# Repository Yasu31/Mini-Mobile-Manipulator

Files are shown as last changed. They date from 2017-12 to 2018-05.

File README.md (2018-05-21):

# Mini Mobile Manipulator
storage for Individual Projects(自主プロ) at UTokyo

## [Progress is documented in the wiki.](https://github.com/Yasu31/fantastic-octo-parakeet/wiki)

## demo
general run-through of robot
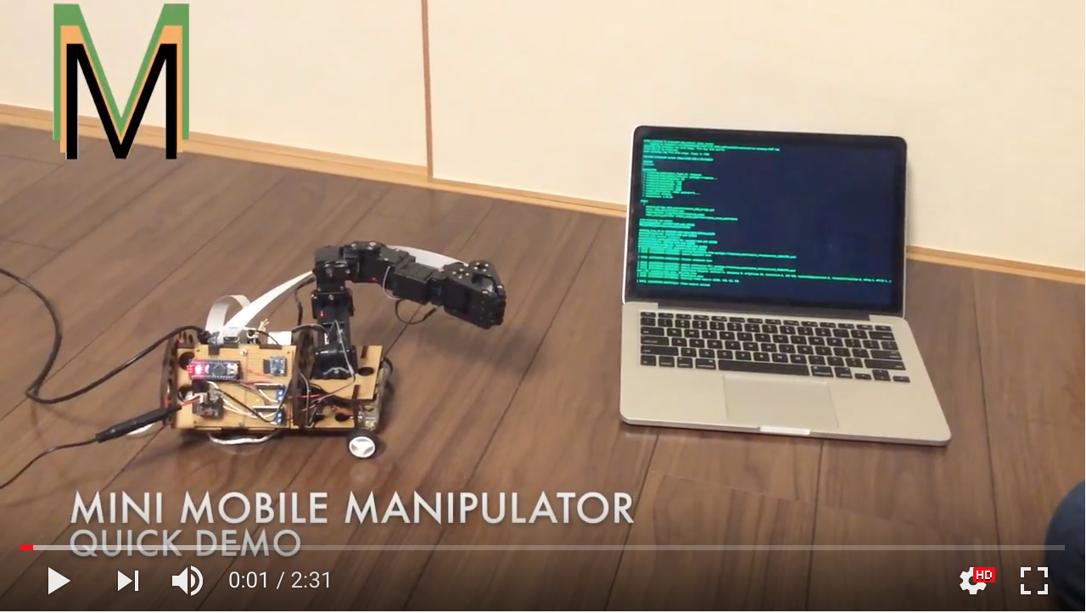
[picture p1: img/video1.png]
(https://www.youtube.com/watch?v=AJrDMAA22wg)


pick up trash(kind of)
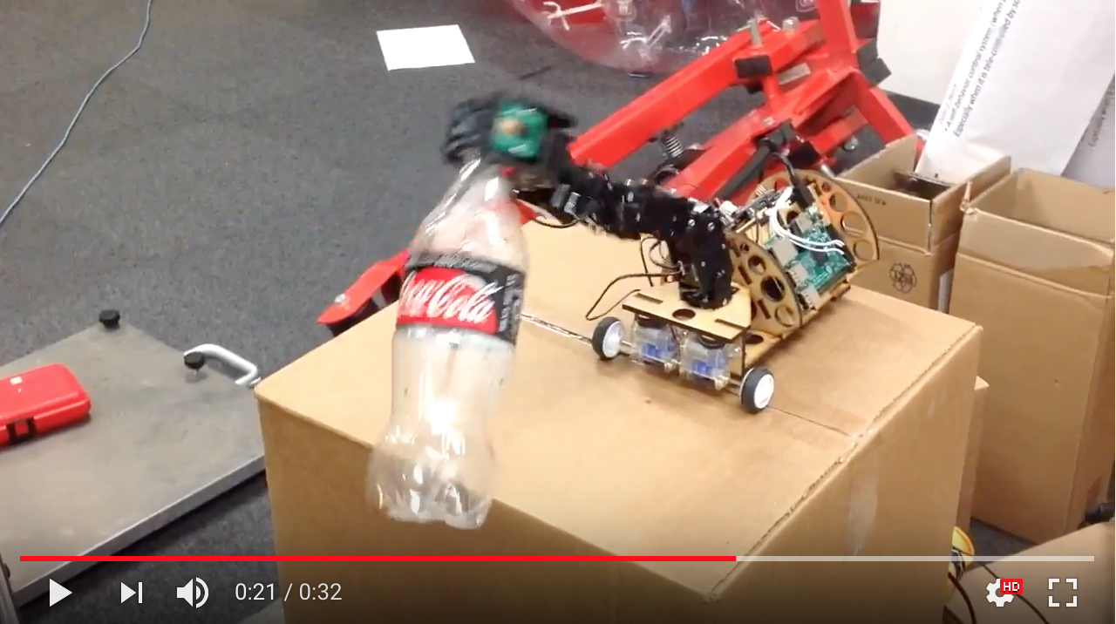
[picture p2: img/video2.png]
(https://www.youtube.com/watch?v=ZHt5yPhyLIU)


## documents
### final report for school project(Japanese)
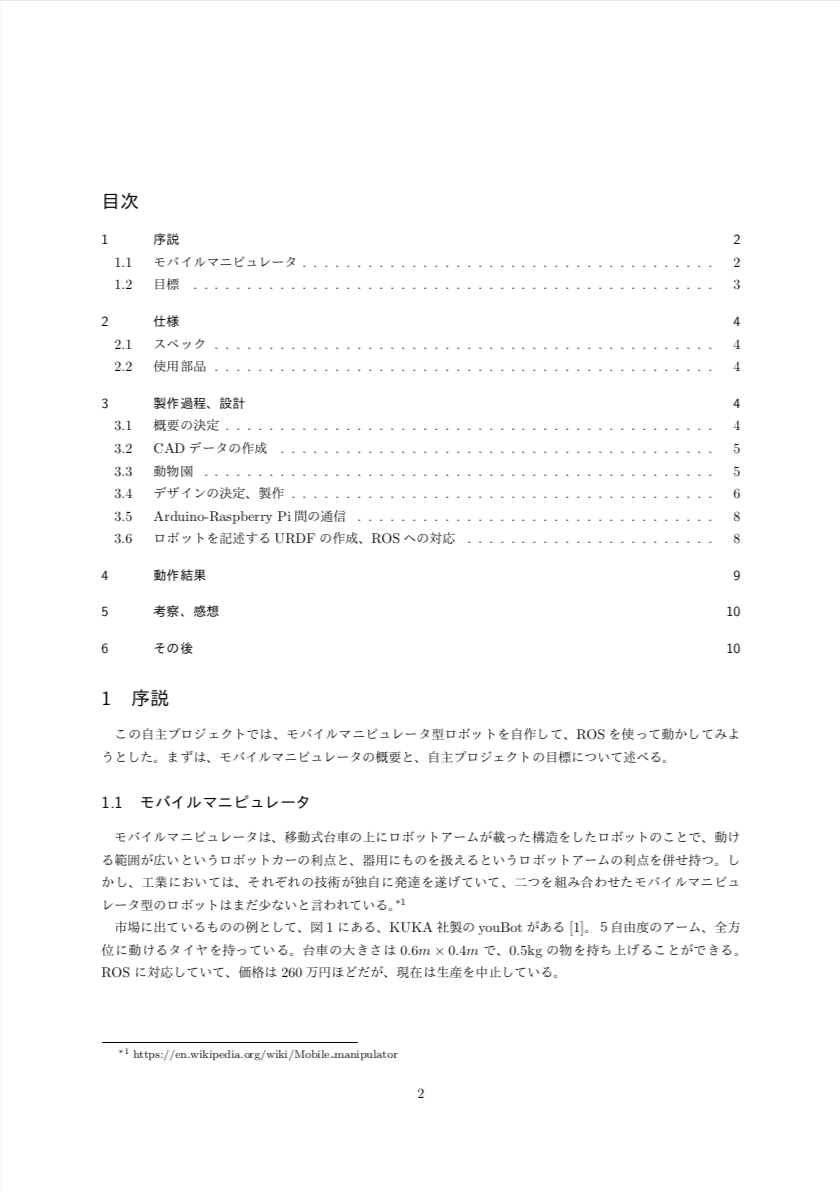
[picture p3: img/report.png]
report_image


## To move the robot(as of Jan.10)
* make sure to be on the same network as robot(NOT eduroam)
* For VM Ubuntu, set ROS_MASTER_URI to http://(IP of raspi):11311 inside ~/.bashrc, set robot_ip on moveit_planning_execution.launch to (IP of raspi).
* `roslaunch mmm_control robot.launch` on RasPi, which launches roscore, handles communication between Arduino, and audio, and ...
* `roslaunch mmm_moveit_config moveit_planning_execution.launch` which starts MoveIt and RVIZ.
* `rosrun image_view image_view image:=/raspicam_node/image _image_transport:=compressed` to view camera feed

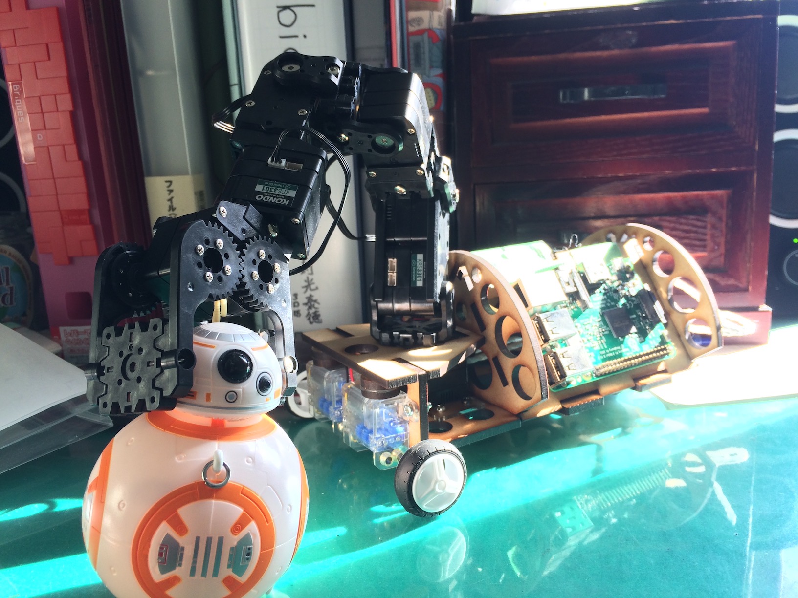
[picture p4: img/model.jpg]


careful- the MMM currently sources the  setup file  for the ice-cream catkin_ws!

## To Move the robot (for MayFes)
* make sure to be on same network as robot
* on the computer (not RasPi), set ROS_MASTER_URI to http://(IP of raspi):11311 inside ~/.bashrc

1. Run `roslaunch mmm_control robot.launch`on the robot. This will launch the arduino connection and the camera and QR code&circle tracking nodes.
1. `python pagekite.py 5000 sub-yasu31.pagekite.me` on the PC will let it become a server for the LINE chatbot.
1. Run `python3 bot.py` the same computer that runs pagekite.py, this will start the LINE chatbot. This will publish stuff to the /command ros topic accordingly to control the robot.
1. Run `roslaunch mayfes behavior.py` (on the robot, if the communication is unstable) to start the actual behavior created for MayFes. This listens in on the /command ROS topic, and takes steps to realize that behavior.
1. run `roslaunch mayfes behavior.launch` on the PC.

### some tips(??)
I am having a hard time launching the MoveIt! stuff. As suggested on this page, I tried [sudo apt install ros-kinetic*](https://answers.ros.org/question/253506/unable-to-connect-to-move_group-action-server-pickup-within-allotted-time/). It didn't work, it may be an issue with the eduroam security settings or something. I'm pretty sure the same thing worked at home. Oh well, I deleted all the moveit stuff from my code so it's all right now.

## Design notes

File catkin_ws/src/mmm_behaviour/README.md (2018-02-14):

# mmm_behaviour
(watch out for the British spelling, I don't know why I did that)

This is the catkin package for the jsk semi demo.
# to use
On raspberry pi,
```
$ roslaunch mmm_behaviour robot.launch
```
This launches
* `mmm_control robot.launch`(which turns on Arduino communication, RasPi camera, audio, and loads the robot URDF.)
* `image_transport republish`(which listens to /raspicam_node/image/compressed and outputs /raspicam_node/image/image_raw. This is required because AR_track_alvar only listens to raw images. cf:[image_transport](http://wiki.ros.org/image_transport#Library_ROS_API), [node tag in launch files](http://wiki.ros.org/roslaunch/XML/node))
* the AR_track_alvar node(that recognizes AR markers)
* the kxr_hand.py script(which creates the kxr_hand frame, which is positioned relative to the ar marker. cf: [Adding a tf frame](http://wiki.ros.org/tf/Tutorials/Adding%20a%20frame%20%28Python%29))

# structure
## what it does(high-level)
Sees a KXR robot, approaches it, then grabs the thing in KXR's hand, then stores it in MMM's basket.

## what it does(middle-level)
### while the KXR robot can't be seen
if it can't recognize KXR(the AR marker on its chest, to be precise), it wanders around the room looking around.
### when it's found
Once it's located, it approaches KXR based on an algorithm similar what was described in the subsumption architecture robot soccer paper. The camera on the arm is locked on to the AR marker.
### when it's close enough
It opens its hand(which also makes it stop), reaches for KXR's hand(which can be calculated using the relative displacement between AR marker and hand), and closes hand.
### when it closes hand
This peculiar condition is inspired by Herbert the robot. When it closes its hand, The arm is retracted to place what it's holding, into the basket.

## what it does (low-level)
It is based on the subsumption architecture.
### arm
#### default(lowest level)
Pose is "look_forward" but the first servo is rotated around.

Hand is relaxed
#### look(second level)
##### trigger: targetRecognized()
when a marker is detected. This is done by :listening to /visualization_marker, and when it is called, updates the variable markerLastReceived with the current time. When targetRecognized() is called, it compares current time with markerLastReceived, and when it hasn't passed 0.3 seconds after last marker receive, returns True.
##### behaviour

Hand is relaxed.
#### grab(likewise)
##### trigger: targetGrabbable()
first, checks with targetRecognized() to see if target is currently seen. Then, uses the tf listener(cf:[Writing a tf listener (Python)](http://wiki.ros.org/tf/Tutorials/Writing%20a%20tf%20listener%20%28Python%29)) to get the transform between the /base frame and /kxr_hand frame. If xy distance is within 0.15m, returns true.
##### behaviour

Hand is open, reach, hand is closed
#### store
##### trigger: handClosed()
get current joint values of the "gripper" move group(which has just one joint) (cf: [Move Groupt Python tutorial](http://docs.ros.org/hydro/api/pr2_moveit_tutorials/html/planning/scripts/doc/move_group_python_interface_tutorial.html)- "Planning to a joint-space goal"),
##### behaviour
Hand is closed, move hand, hand is open, wait one second, hand is default
### hand
#### default
If not within range of ??~??, change to ??

If it is, keep it relaxed
#### open
##### trigger: targetGrabbable()
##### behaviour
opens hand wide. (relax afterwards)
#### closed
##### trigger:

### wheels
#### default
wander around

#### clockwise turn
##### trigger: ???()
uses the [transformations.py library](https://github.com/ros/geometry/blob/hydro-devel/tf/src/tf/transformations.py) available within tf, to compute euler angles, to see how much angle there is between robot and target

# some more links
* no matter how many times I read this I'll never remember how to write it http://wiki.ros.org/ROS/Tutorials/WritingPublisherSubscriber%28python%29
* source code for moveit_commander https://github.com/ros-planning/moveit/blob/kinetic-devel/moveit_commander/src/moveit_commander/move_group.py
* MoveIt python Tutorial http://docs.ros.org/kinetic/api/moveit_tutorials/html/doc/pr2_tutorials/planning/scripts/doc/move_group_python_interface_tutorial.html

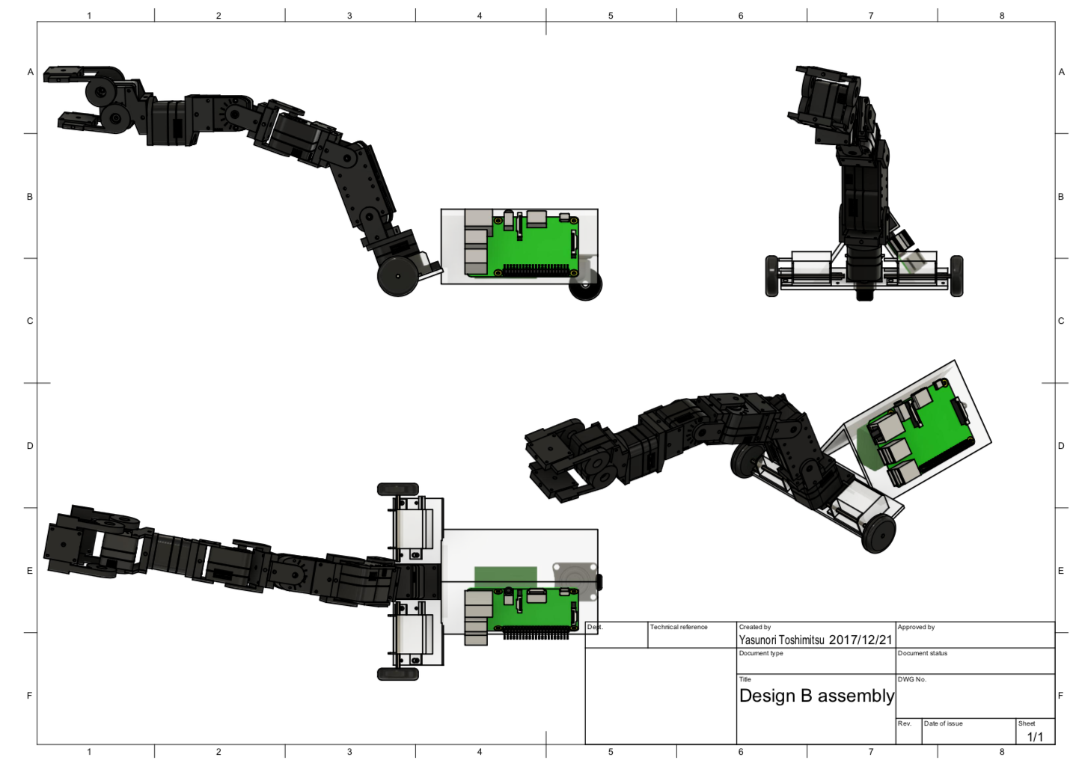
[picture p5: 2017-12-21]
img/designB.png

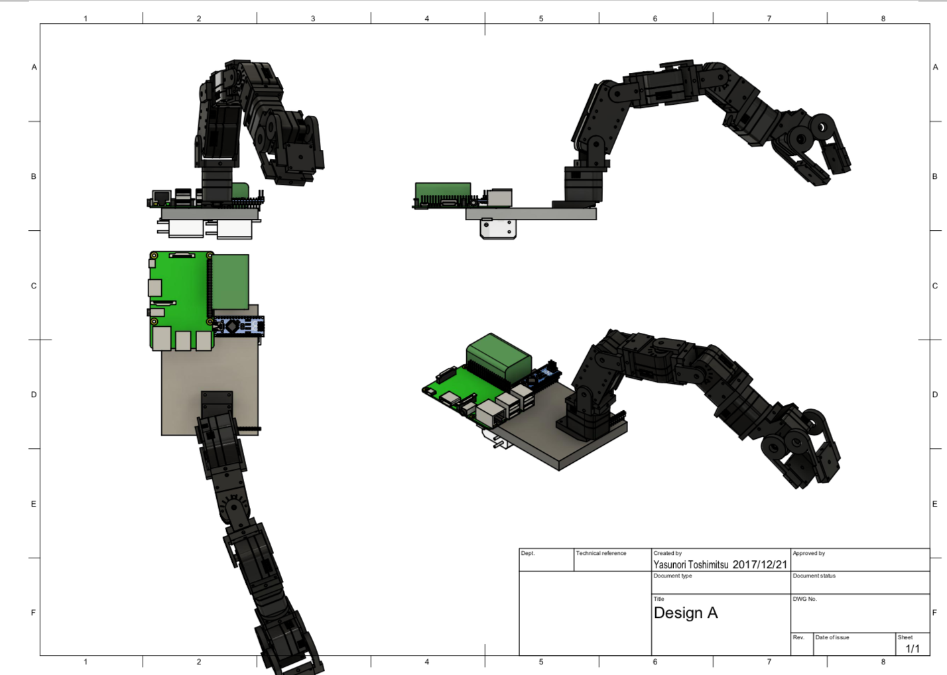
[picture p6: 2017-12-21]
img/designA.png

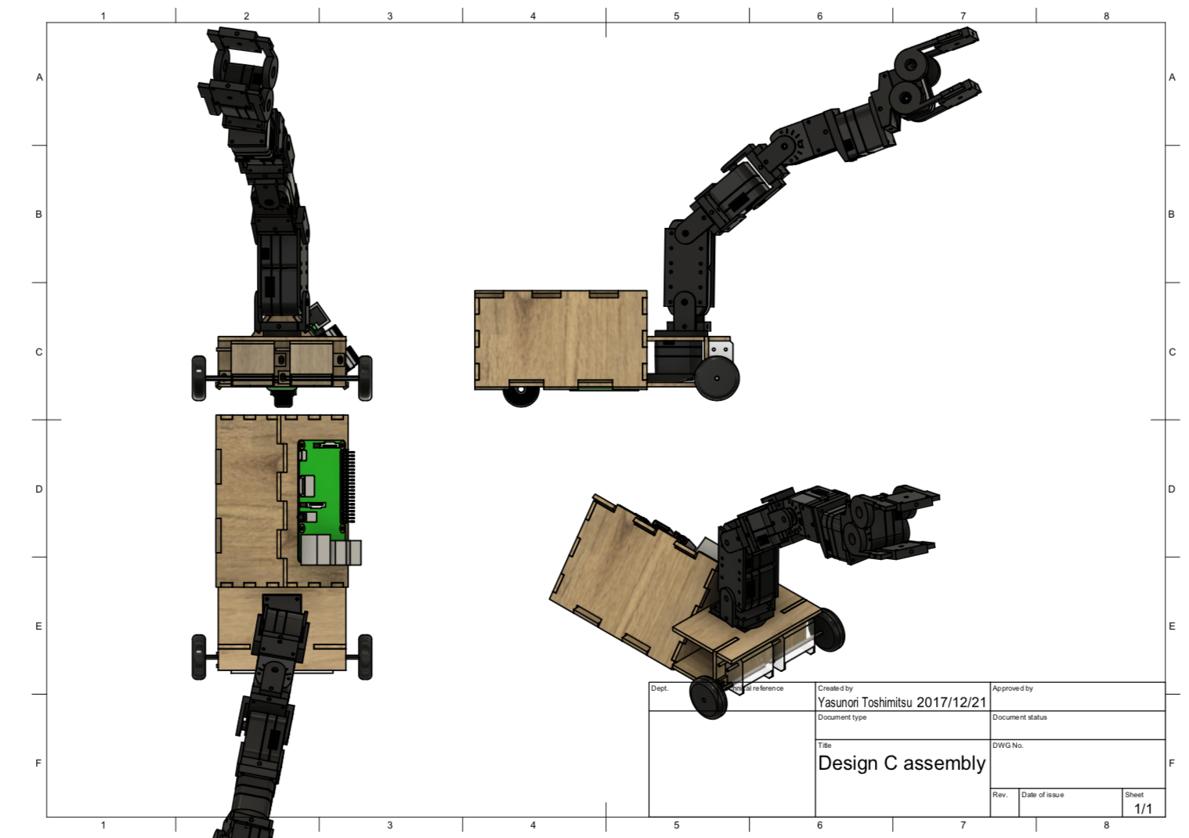
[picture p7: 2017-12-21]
img/designC.png

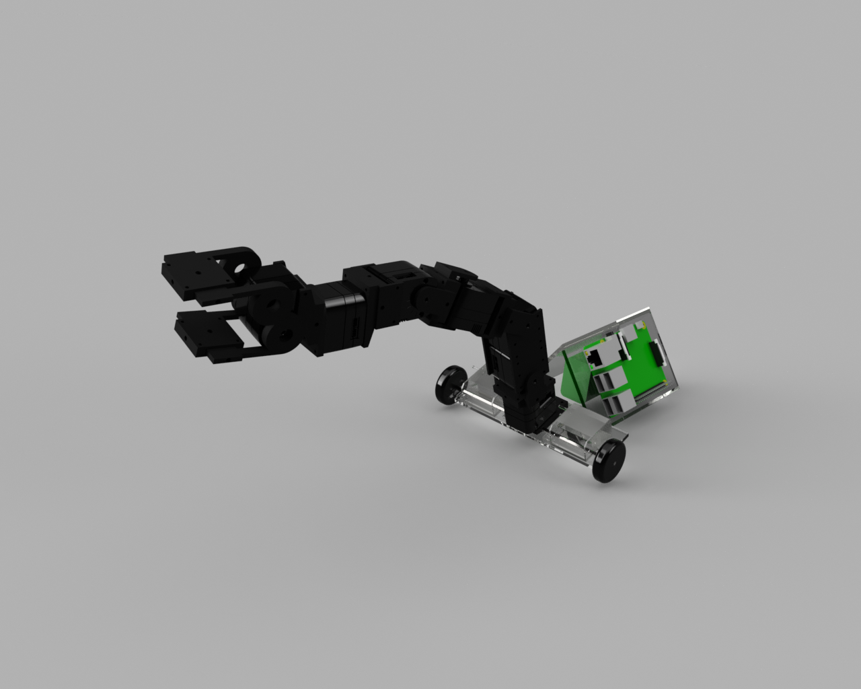
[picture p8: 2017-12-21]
img/designB_render.png

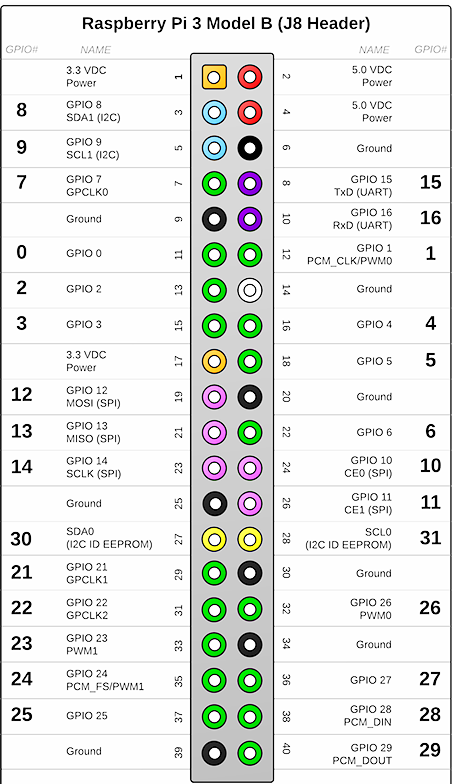
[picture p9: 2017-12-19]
img/raspi.png

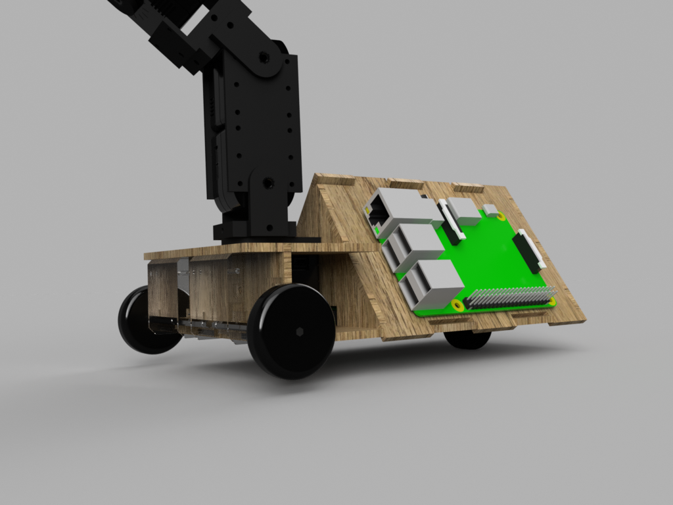
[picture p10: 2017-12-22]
img/modelC_render2.png

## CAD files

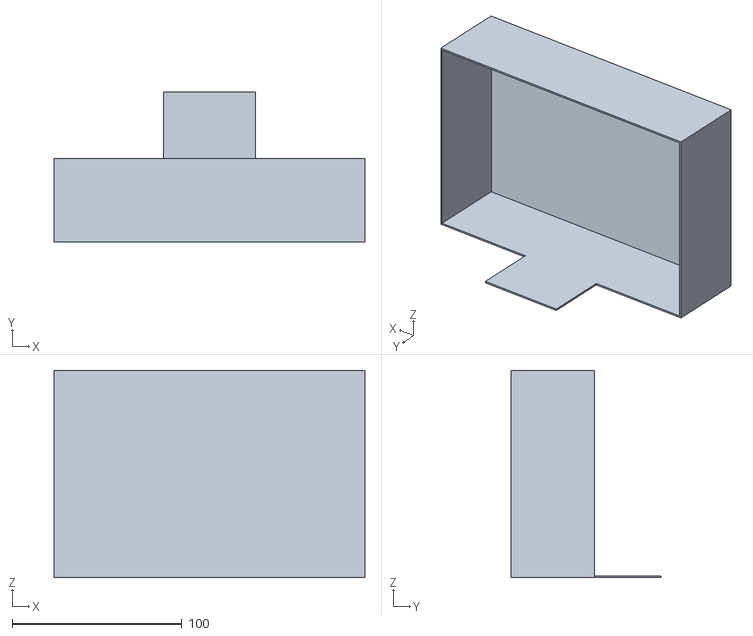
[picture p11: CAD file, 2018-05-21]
catkin_ws/src/mayfes/meshes/candy_box.stl
183.0 x 88.0 x 122.0

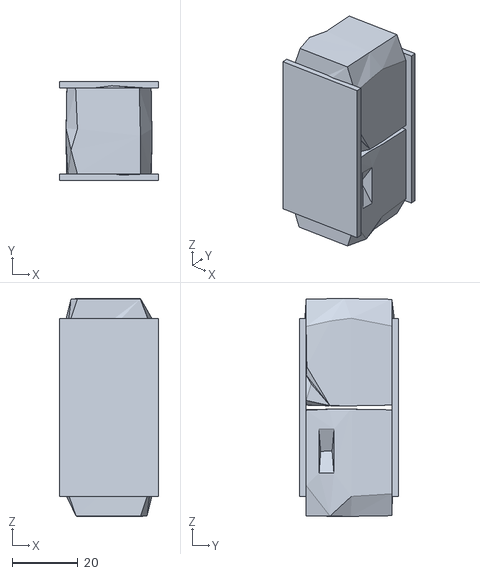
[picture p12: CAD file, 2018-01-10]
catkin_ws/src/mmm_description/meshes/Slink2.stl
30.0 x 30.0 x 66.1

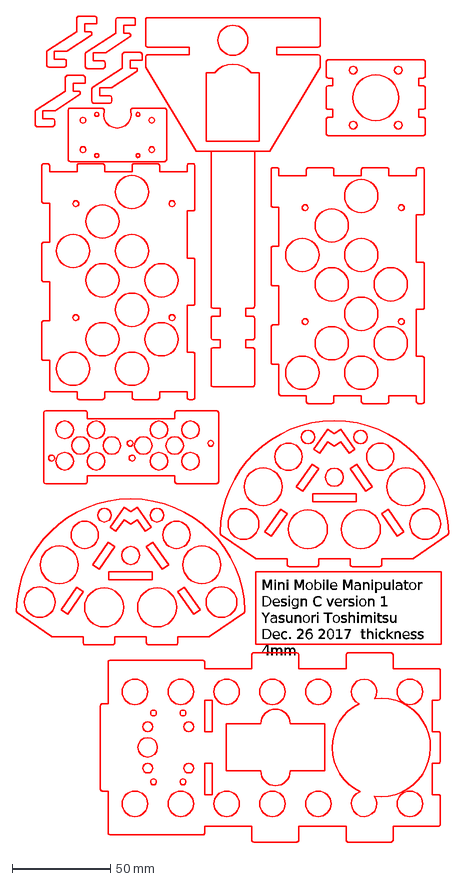
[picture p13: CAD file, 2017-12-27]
Laser Cut Data/design C v1/all parts.dxf
Mini Mobile Manipulator Design C version 1 Yasunori Toshimitsu Dec. 26 2017 thickness 4mm

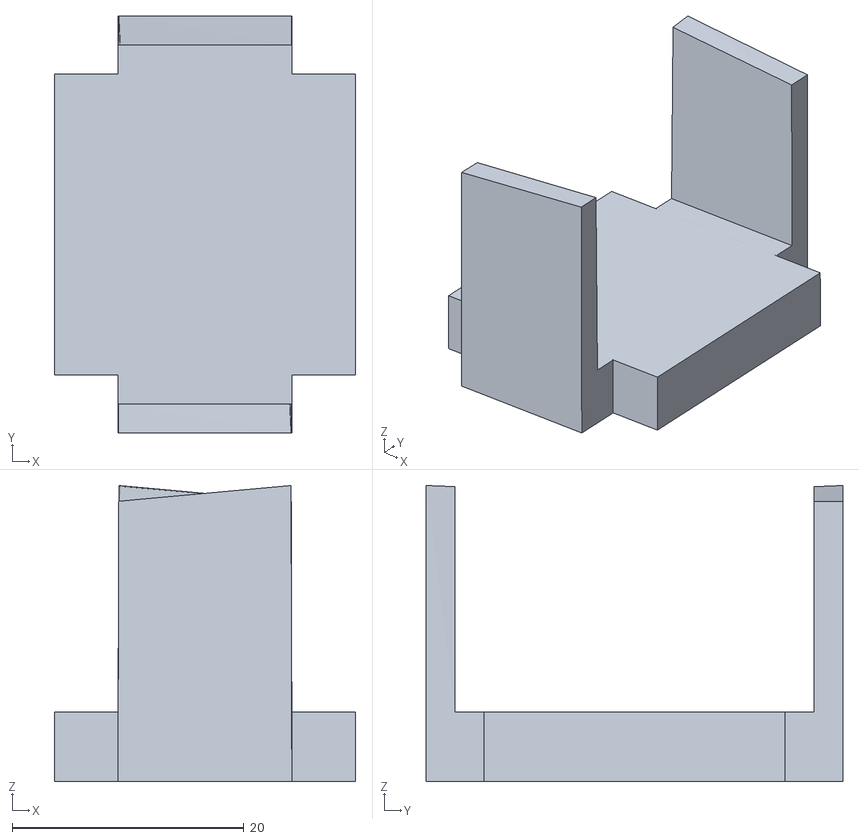
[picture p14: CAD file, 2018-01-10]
catkin_ws/src/mmm_description/meshes/Slink1.stl
26.0 x 36.0 x 25.6

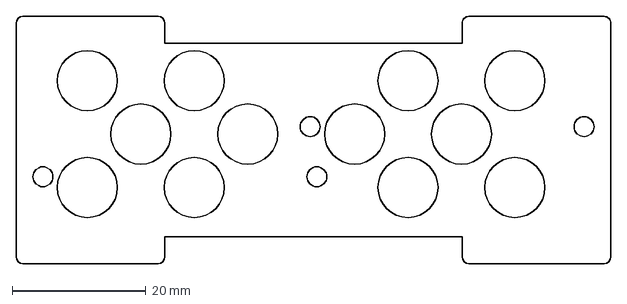
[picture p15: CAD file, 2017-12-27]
Laser Cut Data/design C v1/gearbox plate.dxf
89.0 x 37.0 mm

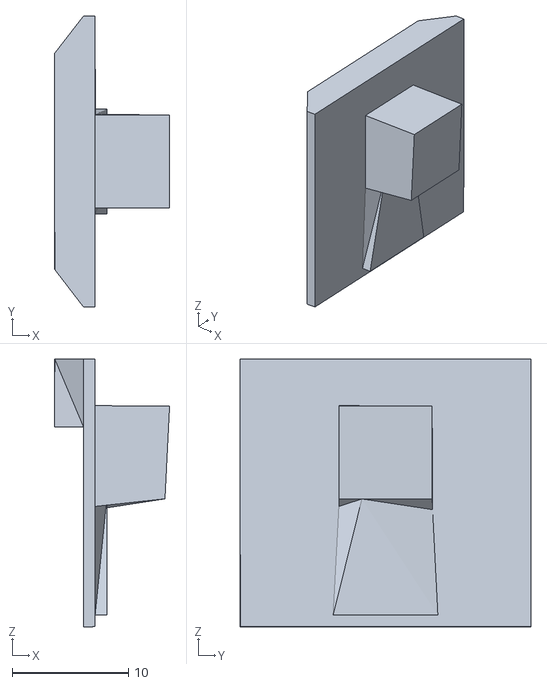
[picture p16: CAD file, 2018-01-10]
catkin_ws/src/mmm_description/meshes/Scamera.stl
9.90 x 25.0 x 23.0

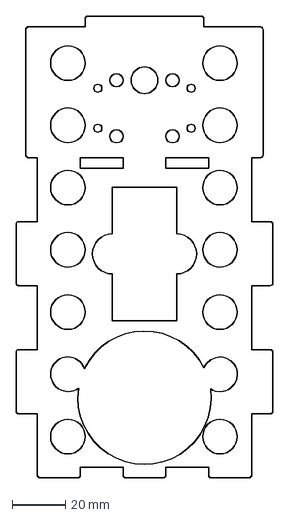
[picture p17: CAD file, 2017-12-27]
Laser Cut Data/design C v1/diagonal bottom.dxf
96.3 x 173.0 mm

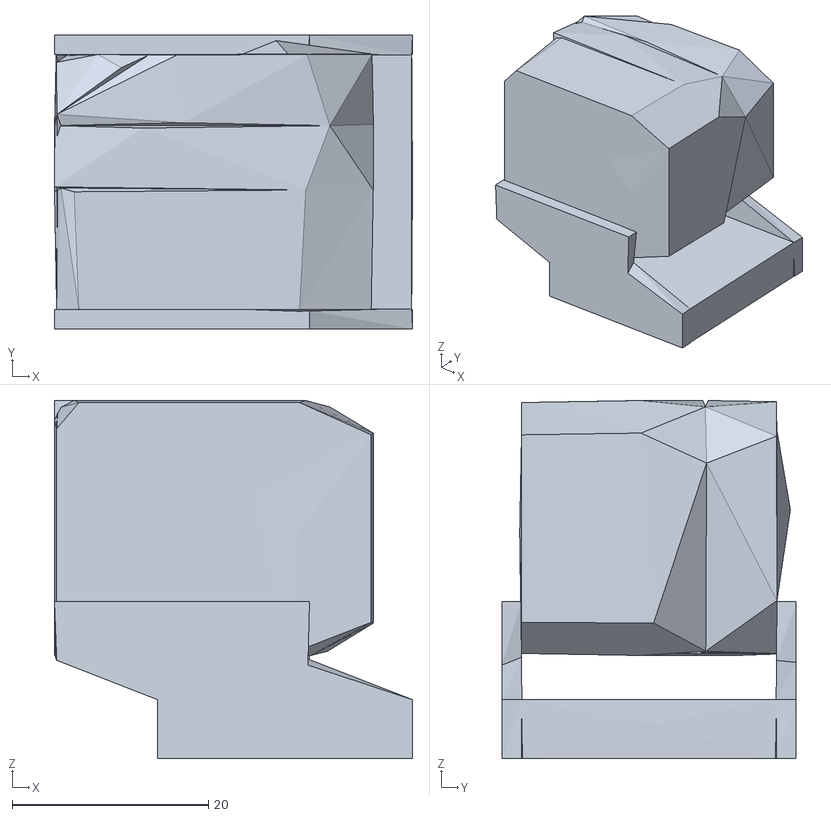
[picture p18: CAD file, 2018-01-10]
catkin_ws/src/mmm_description/meshes/Slink6.stl
36.5 x 30.0 x 36.5

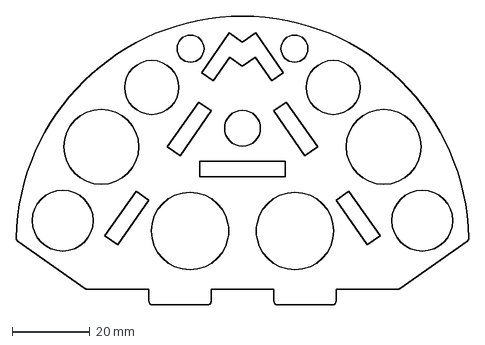
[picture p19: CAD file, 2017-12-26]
Laser Cut Data/design C v1/triangle.dxf
116.4 x 74.3 mm

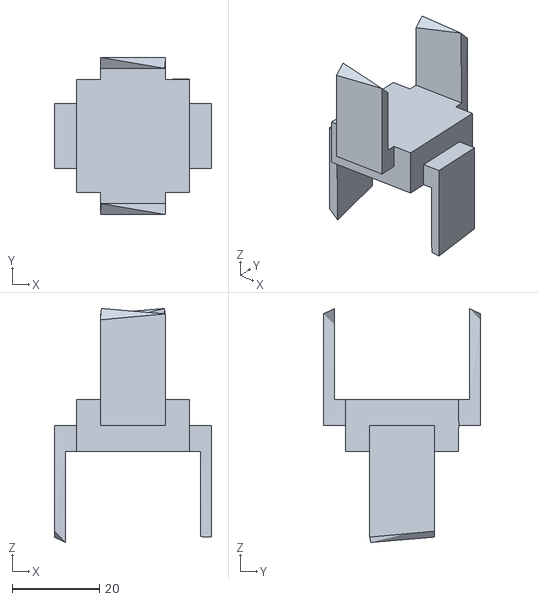
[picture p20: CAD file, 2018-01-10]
catkin_ws/src/mmm_description/meshes/Slink4.stl
36.0 x 36.0 x 53.6

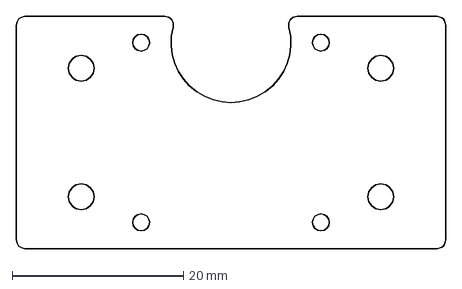
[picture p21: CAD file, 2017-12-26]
Laser Cut Data/design C v1/arm mount.dxf
50.1 x 27.1 mm

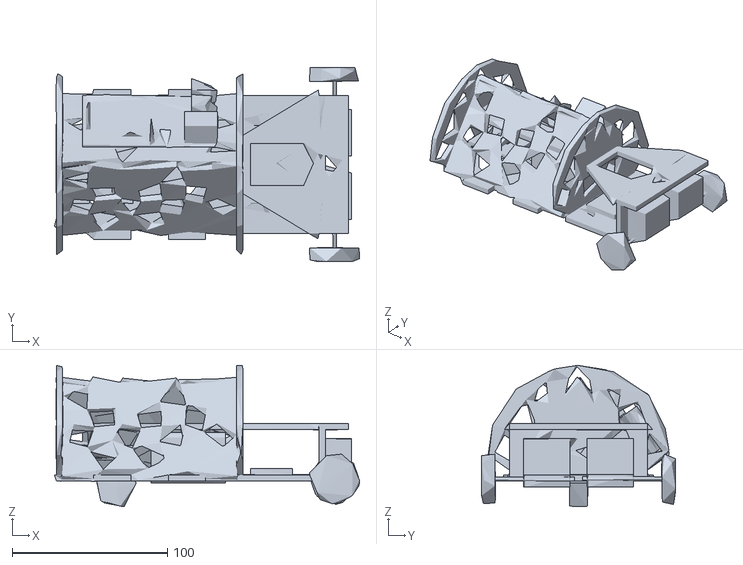
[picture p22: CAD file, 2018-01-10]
catkin_ws/src/mmm_description/meshes/Sbase.stl
196.2 x 125.0 x 90.9

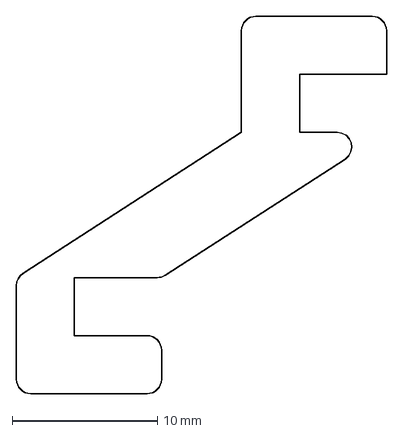
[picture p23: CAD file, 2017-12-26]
Laser Cut Data/design C v1/rear wheel link.dxf
25.5 x 26.0 mm

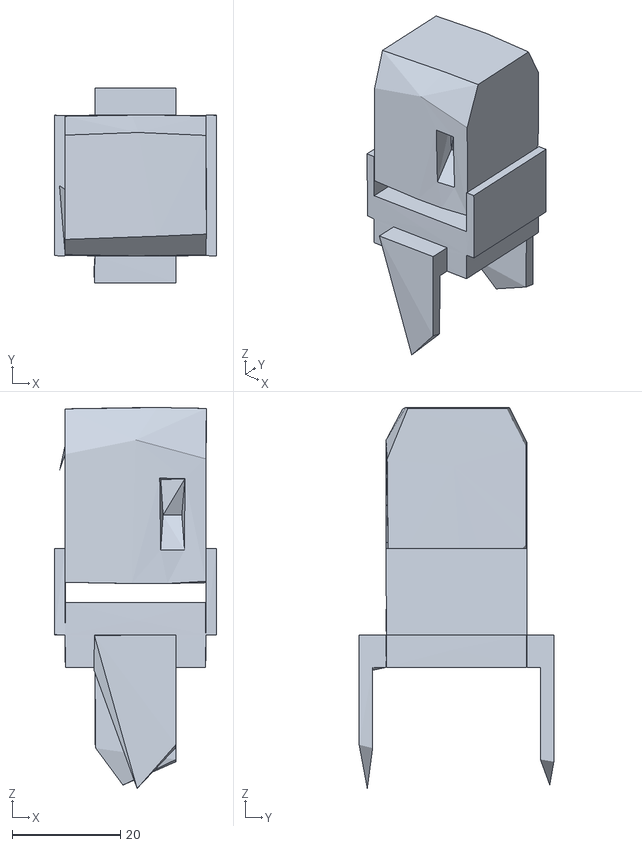
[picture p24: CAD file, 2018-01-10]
catkin_ws/src/mmm_description/meshes/Slink3.stl
30.0 x 36.0 x 70.4

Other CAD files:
Laser Cut Data/design C v1/rear wheel board.dxf
catkin_ws/src/mmm_description/meshes/Slink0.stl
Laser Cut Data/design C v1/middle board.dxf
catkin_ws/src/mmm_description/meshes/Slink7.stl
Laser Cut Data/design C v1/all parts.dwg
Laser Cut Data/design C v1/diagonal board.dxf
catkin_ws/src/mmm_description/meshes/Slink5.stl
catkin_ws/src/mmm_description/meshes/base.stl
catkin_ws/src/mmm_description/meshes/camera.stl
catkin_ws/src/mmm_description/meshes/link0.stl
catkin_ws/src/mmm_description/meshes/link1.stl
catkin_ws/src/mmm_description/meshes/link2.stl
catkin_ws/src/mmm_description/meshes/link3.stl
catkin_ws/src/mmm_description/meshes/link4.stl
catkin_ws/src/mmm_description/meshes/link5.stl
catkin_ws/src/mmm_description/meshes/link6.stl
catkin_ws/src/mmm_description/meshes/link7.stl

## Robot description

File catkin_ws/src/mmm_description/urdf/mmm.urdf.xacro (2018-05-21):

<?xml version="1.0"?>
<robot name="mmm" xmlns:xacro="http://www.ros.org/wiki/xacro">
  <xacro:property name="PI" value="3.141592"/>
  <!-- Joints Control in Gazebo -->
  <gazebo>
    <plugin name="gazebo_ros_control" filename="libgazebo_ros_control.so"/>
  </gazebo>

  <!-- macro to generate a link model -->
  <!-- reads STL at mmm_description/meshes, and positions it at x,y,z -->
  <xacro:macro name="create_link" params="index">
    <link name="link${index}">
      <visual>
        <geometry>
          <!-- the STL is exported from Fusion 360 in millimeters, while URDF expects it in meters.
        Therefore, scaling is required. -->
          <mesh scale="0.001 0.001 0.001" filename="package://mmm_description/meshes/link${index}.stl"/>
        </geometry>
        <material name="gray"/>
      </visual>

      <collision>
      <geometry>
        <!-- the STL is exported from Fusion 360 in millimeters, while URDF expects it in meters.
      Therefore, scaling is required. -->
        <mesh scale="0.001 0.001 0.001" filename="package://mmm_description/meshes/Slink${index}.stl"/>
      </geometry>
      </collision>
<!--
      <inertial>

      </inertial> -->
    </link>
  </xacro:macro>

  <!-- creates a link between link {index-1} and {index} -->
  <!-- input distances in millimeters. -->
  <xacro:macro name="create_joint" params="index x:=0 y:=0 z:=0 axis angle">
    <joint name="link${index-1}_link${index}_joint" type="revolute">
      <parent link="link${index-1}"/>
      <child link="link${index}"/>
      <origin xyz="${x/1000} ${y/1000} ${z/1000}"/>
      <axis xyz="${axis}"/>
      <limit effort="40.0" velocity="1.0" lower="${-angle*PI/180}" upper="${angle*PI/180}"/>
    </joint>
  </xacro:macro>


  <!-- Materials -->
  <material name="brown">
    <color rgba="0.87 0.72 0.53 1.00"/>
  </material>

  <material name="gray">
    <color rgba="0.90 0.90 0.90 1.00"/>
  </material>

  <!-- World frame (for Gazebo) -->
  <link name="world"/>

  <!-- Base fixed to world frame -->
  <joint name="world_base_joint" type="fixed">
    <parent link="world"/>
    <child link="base"/>
  </joint>

  <link name="base">
    <visual>
      <origin xyz="0 0 0" rpy="0 0 0"/>
      <geometry>

        <!-- the STL is exported from Fusion 360 in millimeters, while URDF expects it in meters.
      Therefore, scaling is required. -->
        <mesh scale="0.001 0.001 0.001" filename="package://mmm_description/meshes/base.stl"/>
      </geometry>
      <material name="brown"/>
    </visual>

    <collision>
      <geometry>

        <!-- the STL is exported from Fusion 360 in millimeters, while URDF expects it in meters.
      Therefore, scaling is required. -->
        <mesh scale="0.001 0.001 0.001" filename="package://mmm_description/meshes/Sbase.stl"/>
      </geometry>
    </collision>

    <!-- <inertial>
    </inertial> -->
  </link>

  <joint name="base_link0_joint" type="fixed">
    <parent link="base"/>
    <child link="link0"/>
    <origin xyz="${-30.2/1000} ${0/1000} ${6.9/1000}"/>
  </joint>
  <xacro:create_link index="0"/>


  <xacro:create_joint index="1" z="31" axis="0 0 1" angle="135"/>
  <xacro:create_link index="1"/>


  <xacro:create_joint index="2" y="15.46" z="20.25" axis="0 1 0" angle="60"/>
  <xacro:create_link index="2"/>

  <xacro:create_joint index="3" z="48" axis="0 1 0" angle="60"/>
  <xacro:create_link index="3"/>

  <xacro:create_joint index="4" x="13.72" y="-15.5" z="53.22" axis="1 0 0" angle="90"/>
  <xacro:create_link index="4"/>

  <xacro:create_joint index="5" x="-15.8" y="-15.9" z="40" axis="0 1 0" angle="90"/>
  <xacro:create_link index="5"/>

  <xacro:create_joint index="6" y="13.9" z="69.5" axis="0 0 1" angle="135"/>
  <xacro:create_link index="6"/>

  <joint name="link6_gripper_frame_joint" type="fixed">
    <parent link="link6" />
    <child link="gripper_frame"/>
    <origin xyz="0 0 ${50/1000}"/>
  </joint>
  <link name="gripper_frame">
  </link>

  <xacro:create_joint index="7" y="-13.9" z="23.5" axis="0 1 0" angle="20">
  </xacro:create_joint>
  <xacro:create_link index="7"/>



  <joint name="link6_link7b_joint" type="revolute">
    <parent link="link6"/>
    <child link="link7b"/>
    <origin xyz="${-20.97/1000} ${13.04/1000} ${34/1000}" rpy="0 0 ${PI}"/>
    <axis xyz="0 1 0"/>
    <limit effort="40.0" velocity="1.0" lower="${-PI}" upper="${PI}"/>
    <mimic joint="link6_link7_joint" offset="${-PI*50/180}"/>
  </joint>
  <link name="link7b">
    <visual>
      <geometry>
        <!-- the STL is exported from Fusion 360 in millimeters, while URDF expects it in meters.
      Therefore, scaling is required. -->
        <mesh scale="0.001 0.001 0.001" filename="package://mmm_description/meshes/link7.stl"/>
      </geometry>
      <material name="gray"/>
    </visual>

    <collision>
      <geometry>
        <!-- the STL is exported from Fusion 360 in millimeters, while URDF expects it in meters.
      Therefore, scaling is required. -->
        <mesh scale="0.001 0.001 0.001" filename="package://mmm_description/meshes/Slink7.stl"/>
      </geometry>

    </collision>

    <!-- <inertial>

    </inertial> -->
  </link>

  <joint name="link7b_camera_mesh_joint" type="fixed">
    <parent link="link7b"/>
    <child link="camera_mesh"/>
    <origin xyz="${21/1000} ${14.93/1000} ${13.9/1000}" rpy="0 ${25*PI/180} 0"/>
  </joint>

  <link name="camera_mesh">
    <visual>
      <origin xyz="0 0 0" rpy="0 0 0"/>
      <geometry>
        <!-- the STL is exported from Fusion 360 in millimeters, while URDF expects it in meters.
      Therefore, scaling is required. -->
        <mesh scale="0.001 0.001 0.001" filename="package://mmm_description/meshes/camera.stl"/>
      </geometry>
      <material name="brown"/>
    </visual>
    <!--
    <collision>
    </collision>

    <inertial>
    </inertial> -->
  </link>

  <link name="camera"/>
  <joint name="camera_mesh_camera_joint" type="fixed">
    <parent link="camera_mesh"/>
    <child link="camera"/>
    <origin xyz="0 0 0" rpy="${-PI/2} 0 ${-PI/2}"/>
  </joint>

</robot>

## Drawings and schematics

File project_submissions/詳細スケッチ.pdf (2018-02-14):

H29 自主プロコンセプト詳細スケッチ | 学籍番号 | 名前
12/22 演習室 13C にて提出のこと!! | （アドバイザ担当教職員 group： | *staff 記入欄）

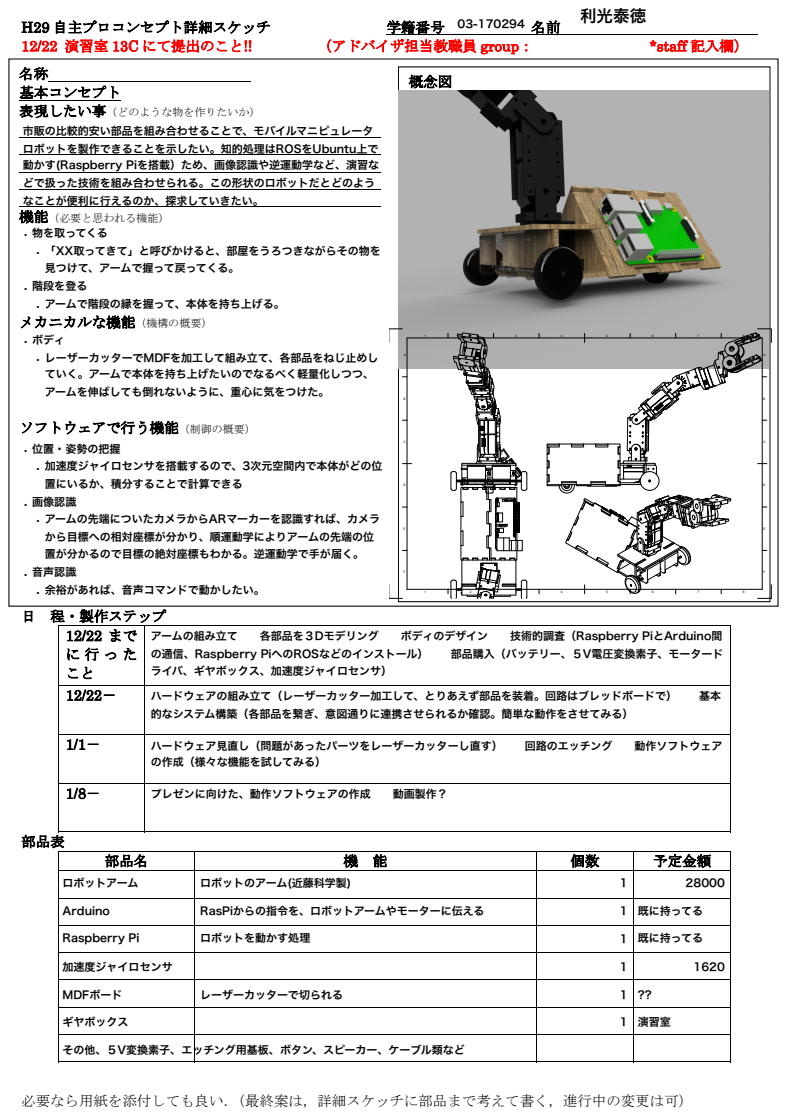
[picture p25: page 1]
日 程・製作ステップ; 部品表; 名称 基本コンセプト; 表現したい事（どのような物を作りたいか）; ソフトウェアで行う機能（制御の概要）; 概念図; 利光泰徳; • 位置・姿勢の把握; • 加速度ジャイロセンサを搭載するので、3次元空間内で本体がどの位; 置にいるか、積分することで計算できる; • 画像認識 • アームの先端についたカメラからARマーカーを認識すれば、カメラ; から目標への相対座標が分かり、順運動学によりアームの先端の位; 置が分かるので目標の絶対座標もわかる。逆運動学で手が届く。; • 音声認識; • 余裕があれば、音声コマンドで動かしたい。

市販の比較的安い部品を組み合わせることで、モバイルマニピュレータ
ロボットを製作できることを示したい。知的処理はROSをUbuntu上で
動かす(Raspberry Piを搭載）ため、画像認識や逆運動学など、演習な
どで扱った技術を組み合わせられる。この形状のロボットだとどのよう
なことが便利に行えるのか、探求していきたい。
機能（必要と思われる機能）
• 物を取ってくる
• 「XX取ってきて」と呼びかけると、部屋をうろつきながらその物を
見つけて、アームで握って戻ってくる。
• 階段を登る
• アームで階段の縁を握って、本体を持ち上げる。
メカニカルな機能（機構の概要）
• ボディ
• レーザーカッターでMDFを加工して組み立て、各部品をねじ止めし
ていく。アームで本体を持ち上げたいのでなるべく軽量化しつつ、
アームを伸ばしても倒れないように、重心に気をつけた。

12/22 まで に行った こと | アームの組み立て　　各部品を３Dモデリング　　ボディのデザイン　　技術的調査（Raspberry PiとArduino間 の通信、Raspberry PiへのROSなどのインストール）　　部品購入（バッテリー、５V電圧変換素子、モータード ライバ、ギヤボックス、加速度ジャイロセンサ）

12/22－ | ハードウェアの組み立て（レーザーカッター加工して、とりあえず部品を装着。回路はブレッドボードで）　　基本 的なシステム構築（各部品を繋ぎ、意図通りに連携させられるか確認。簡単な動作をさせてみる）

1/1－ | ハードウェア見直し（問題があったパーツをレーザーカッターし直す）　　回路のエッチング　　動作ソフトウェア の作成（様々な機能を試してみる）

1/8－ | プレゼンに向けた、動作ソフトウェアの作成　　動画製作？

部品名 | 機 能 | 個数 | 予定金額

ロボットアーム | ロボットのアーム(近藤科学製) | 1 | 28000

Arduino | RasPiからの指令を、ロボットアームやモーターに伝える | 1 | 既に持ってる

Raspberry Pi | ロボットを動かす処理 | 1 | 既に持ってる

加速度ジャイロセンサ | | 1 | 1620

MDFボード | レーザーカッターで切られる | 1 | ??

ギヤボックス | | 1 | 演習室

その他、５V変換素子、エッチング用基板、ボタン、スピーカー、ケーブル類など

必要なら用紙を添付しても良い．（最終案は，詳細スケッチに部品まで考えて書く，進行中の変更は可）

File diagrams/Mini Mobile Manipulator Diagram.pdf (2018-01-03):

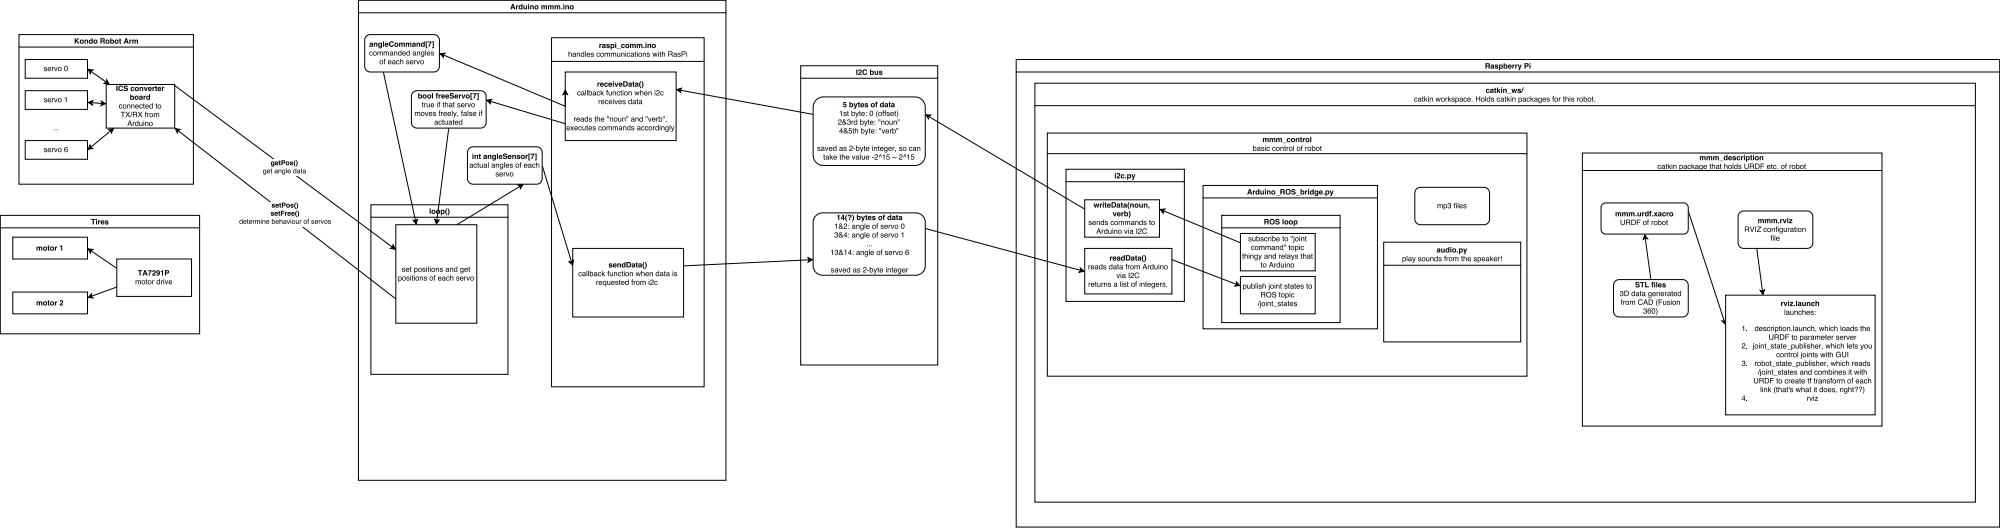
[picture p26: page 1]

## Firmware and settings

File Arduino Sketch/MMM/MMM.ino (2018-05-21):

#include <IcsClass.h>

//https://github.com/sparkfun/LSM9DS1_Breakout/blob/master/Libraries/Arduino/examples/LSM9DS1_Basic_I2C/LSM9DS1_Basic_I2C.ino
#include <LSM9DS1_Types.h>
#include <SparkFunLSM9DS1.h>
#include <LSM9DS1_Registers.h>
#include <Wire.h>

//Slave Address for the Communication
#define SLAVE_ADDRESS 0x04
#define LSM9DS1_M  0x1E // SPIアドレス設定 0x1C if SDO_M is LOW
#define LSM9DS1_AG  0x6B // SPIアドレス設定 if SDO_AG is LOW

#define NUM_SERVOS 7
#define NUM_BYTES 15

int R_PWM=9;
int R_INA=10;
int R_INB=11;

int L_PWM=3;
int L_INA=5;
int L_INB=6;

float gyr[3]={0.0,0.0,0.0};
float acc[3]={0.0,0.0,0.0};
float mag[3]={0.0,0.0,0.0};
LSM9DS1 imu;

float sensorPos[3]={0.0,0.0,0.0};
float sensorOri[4]={0.0,0.0,0.0,0.0};
//in degrees*100
int angleSensor[7]={0,0,0,0,0,0,0};
bool freeServo[7]={true,true,true,true,true,true,true};
//in degrees*100
int angleCommand[7]={0,0,0,0,0,0,0};

bool noSerial=true;
const int enpin = 2;
const long baudrate = 115200;
const int timeout = 5;
IcsClass krs(&Serial,enpin,baudrate,timeout);

void setup() {
  // put your setup code here, to run once:
  if (!noSerial){Serial.begin(115200);}
  //initialize i2c as slave
  Wire.begin(SLAVE_ADDRESS);
  // define callbacks for i2c communication
  Wire.onReceive(receiveData);
  Wire.onRequest(sendData);

  krs.begin();
  for(int i=0; i<7; i++){
    krs.setStrc(i,127);
  }

  pinMode(R_PWM, OUTPUT);
  pinMode(R_INA, OUTPUT);
  pinMode(R_INB, OUTPUT);

  pinMode(L_PWM, OUTPUT);
  pinMode(L_INA, OUTPUT);
  pinMode(L_INB, OUTPUT);




//  imu.settings.device.commInterface = IMU_MODE_I2C;
//  imu.settings.device.mAddress = LSM9DS1_M;
//  imu.settings.device.agAddress = LSM9DS1_AG;
//
//  if (!imu.begin())                                     //センサ接続エラー時の表示
//
//  {
//    Serial.println("Failed to communicate with LSM9DS1.");
//    Serial.println("Double-check wiring.");
//    Serial.println("Default settings in this sketch will " \
//                   "work for an out of the box LSM9DS1 " \
//                   "Breakout, but may need to be modified " \
//                   "if the board jumpers are.");
//    while (1)
//      ;
//  }
}

void loop() {
  // put your main code here, to run repeatedly:
//  readSensor();
//  Serial.print("\nax\t"+String(acc[0])+"\tay\t"+String(acc[1])+"\taz\t"+String(acc[2]));

  // do processes that take some time inside the loop(), so that we can immediately return the servo angles in the i2c callback function
  for(int i=0; i<NUM_SERVOS; i++){
    if(freeServo[i]){
      angleSensor[i]=krs.posDeg100(krs.setFree(i));
    }
    else{
      angleSensor[i]=krs.posDeg100(krs.setPos(i,krs.degPos100(angleCommand[i])));
    }
  }
  delay(1);

}

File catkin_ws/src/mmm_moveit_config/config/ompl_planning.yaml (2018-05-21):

planner_configs:
  SBLkConfigDefault:
    type: geometric::SBL
    range: 0.0  # Max motion added to tree. ==> maxDistance_ default: 0.0, if 0.0, set on setup()
  ESTkConfigDefault:
    type: geometric::EST
    range: 0.0  # Max motion added to tree. ==> maxDistance_ default: 0.0, if 0.0 setup()
    goal_bias: 0.05  # When close to goal select goal, with this probability. default: 0.05
  LBKPIECEkConfigDefault:
    type: geometric::LBKPIECE
    range: 0.0  # Max motion added to tree. ==> maxDistance_ default: 0.0, if 0.0, set on setup()
    border_fraction: 0.9  # Fraction of time focused on boarder default: 0.9
    min_valid_path_fraction: 0.5  # Accept partially valid moves above fraction. default: 0.5
  BKPIECEkConfigDefault:
    type: geometric::BKPIECE
    range: 0.0  # Max motion added to tree. ==> maxDistance_ default: 0.0, if 0.0, set on setup()
    border_fraction: 0.9  # Fraction of time focused on boarder default: 0.9
    failed_expansion_score_factor: 0.5  # When extending motion fails, scale score by factor. default: 0.5
    min_valid_path_fraction: 0.5  # Accept partially valid moves above fraction. default: 0.5
  KPIECEkConfigDefault:
    type: geometric::KPIECE
    range: 0.0  # Max motion added to tree. ==> maxDistance_ default: 0.0, if 0.0, set on setup()
    goal_bias: 0.05  # When close to goal select goal, with this probability. default: 0.05 
    border_fraction: 0.9  # Fraction of time focused on boarder default: 0.9 (0.0,1.]
    failed_expansion_score_factor: 0.5  # When extending motion fails, scale score by factor. default: 0.5
    min_valid_path_fraction: 0.5  # Accept partially valid moves above fraction. default: 0.5
  RRTkConfigDefault:
    type: geometric::RRT
    range: 0.0  # Max motion added to tree. ==> maxDistance_ default: 0.0, if 0.0, set on setup()
    goal_bias: 0.05  # When close to goal select goal, with this probability? default: 0.05
  RRTConnectkConfigDefault:
    type: geometric::RRTConnect
    range: 0.0  # Max motion added to tree. ==> maxDistance_ default: 0.0, if 0.0, set on setup()
  RRTstarkConfigDefault:
    type: geometric::RRTstar
    range: 0.0  # Max motion added to tree. ==> maxDistance_ default: 0.0, if 0.0, set on setup()
    goal_bias: 0.05  # When close to goal select goal, with this probability? default: 0.05
    delay_collision_checking: 1  # Stop collision checking as soon as C-free parent found. default 1
  TRRTkConfigDefault:
    type: geometric::TRRT
    range: 0.0  # Max motion added to tree. ==> maxDistance_ default: 0.0, if 0.0, set on setup()
    goal_bias: 0.05  # When close to goal select goal, with this probability? default: 0.05
    max_states_failed: 10  # when to start increasing temp. default: 10
    temp_change_factor: 2.0  # how much to increase or decrease temp. default: 2.0
    min_temperature: 10e-10  # lower limit of temp change. default: 10e-10
    init_temperature: 10e-6  # initial temperature. default: 10e-6
    frountier_threshold: 0.0  # dist new state to nearest neighbor to disqualify as frontier. default: 0.0 set in setup() 
    frountierNodeRatio: 0.1  # 1/10, or 1 nonfrontier for every 10 frontier. default: 0.1
    k_constant: 0.0  # value used to normalize expresssion. default: 0.0 set in setup()
  PRMkConfigDefault:
    type: geometric::PRM
    max_nearest_neighbors: 10  # use k nearest neighbors. default: 10
  PRMstarkConfigDefault:
    type: geometric::PRMstar
  FMTkConfigDefault:
    type: geometric::FMT
    num_samples: 1000  # number of states that the planner should sample. default: 1000
    radius_multiplier: 1.1  # multiplier used for the nearest neighbors search radius. default: 1.1
    nearest_k: 1  # use Knearest strategy. default: 1
    cache_cc: 1  # use collision checking cache. default: 1
    heuristics: 0  # activate cost to go heuristics. default: 0
    extended_fmt: 1  # activate the extended FMT*: adding new samples if planner does not finish successfully. default: 1
  BFMTkConfigDefault:
    type: geometric::BFMT
    num_samples: 1000  # number of states that the planner should sample. default: 1000
    radius_multiplier: 1.0  # multiplier used for the nearest neighbors search radius. default: 1.0
    nearest_k: 1  # use the Knearest strategy. default: 1
    balanced: 0  # exploration strategy: balanced true expands one tree every iteration. False will select the tree with lowest maximum cost to go. default: 1
    optimality: 1  # termination strategy: optimality true finishes when the best possible path is found. Otherwise, the algorithm will finish when the first feasible path is found. default: 1
    heuristics: 1  # activates cost to go heuristics. default: 1
    cache_cc: 1  # use the collision checking cache. default: 1
    extended_fmt: 1  # Activates the extended FMT*: adding new samples if planner does not finish successfully. default: 1
  PDSTkConfigDefault:
    type: geometric::PDST
  STRIDEkConfigDefault:
    type: geometric::STRIDE
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

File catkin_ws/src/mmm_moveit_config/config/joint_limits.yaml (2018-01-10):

# joint_limits.yaml allows the dynamics properties specified in the URDF to be overwritten or augmented as needed
# Specific joint properties can be changed with the keys [max_position, min_position, max_velocity, max_acceleration]
# Joint limits can be turned off with [has_velocity_limits, has_acceleration_limits]
joint_limits:
  link0_link1_joint:
    has_velocity_limits: true
    max_velocity: 1
    has_acceleration_limits: false
    max_acceleration: 0
  link1_link2_joint:
    has_velocity_limits: true
    max_velocity: 1
    has_acceleration_limits: false
    max_acceleration: 0
  link2_link3_joint:
    has_velocity_limits: true
    max_velocity: 1
    has_acceleration_limits: false
    max_acceleration: 0
  link3_link4_joint:
    has_velocity_limits: true
    max_velocity: 1
    has_acceleration_limits: false
    max_acceleration: 0
  link4_link5_joint:
    has_velocity_limits: true
    max_velocity: 1
    has_acceleration_limits: false
    max_acceleration: 0
  link5_link6_joint:
    has_velocity_limits: true
    max_velocity: 1
    has_acceleration_limits: false
    max_acceleration: 0
  link6_link7_joint:
    has_velocity_limits: true
    max_velocity: 1
    has_acceleration_limits: false
    max_acceleration: 0
  link6_link7b_joint:
    has_velocity_limits: true
    max_velocity: 1
    has_acceleration_limits: false
    max_acceleration: 0

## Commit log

2017-12-19 Add Arduino stuff
2017-12-26 add DXL for design C
    [arm mount.dxf, diagonal board.dxf, diagonal bottom.dxf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]
2017-12-27 add cad data
    [Design C base.stl, all parts.dwg, all parts.dxf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]
2017-12-28 add catkin workspace
    [DesignCbase.stl, mmm.urdf, mmm.urdf.xacro]
2017-12-28 add small stl
    [base.stl]
2017-12-28 add STL and such
    [base.stl, link0.stl, link1.stl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]
2017-12-30 change name of Arduino script, modify i2c code
2017-12-31 add sound files, change i2c code
2017-12-31 reading from Arduino works
2017-12-31 NOW read&write from Arduino actually works
2017-12-31 moved i2c script to catkin_ws/src/mmm_control/scripts
2018-01-02 fix i2c to work with smbus-cffi
    [arduino_ROS_bridge.py]
2018-01-02 change rviz.launch so it doesn't publish joints by itself add meshes and links in URDF
    [link6.stl, link7.stl, mmm.urdf.xacro]
2018-01-02 change Arduino code
    I can now set servos free or actuated.
2018-01-08 add raspicam_node package, add camera STL and edited URDF, add launch file
    [Camera.cfg, camera.stl, mmm.urdf.xacro]
2018-01-08 fixed audio.py so it isn't executed while omxplayer is running
    [audio.py]
2018-01-08 move i2c code within same script
2018-01-09 add moveit files
    [Sbase.stl, Scamera.stl, Slink0.stl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]
2018-01-10 Add poses, action server, and more *fun* stuff
    [controllers.yaml]
2018-01-10 Add simpler meshes, logo, presentation
    [Sbase.stl, Scamera.stl, Slink0.stl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]
2018-01-29 fix camera origin
    [mmm.urdf.xacro]
2018-01-29 fix camera again
    [mmm.urdf.xacro]
2018-01-29 various changes...
    [mmm.urdf.xacro]
2018-01-29 commit from Pi
    [mmm.urdf.xacro]
2018-01-30 add ros topic to directly control joint0
2018-01-30 lots of changes.
    [mmm.urdf.xacro]
2018-02-01 docs: add videos, final report for 自主プロ
2018-04-22 feat: "simulation", actual action server, bridge now listens to /joint_states
2018-04-22 feat: print check sum (it's not working...)
    [arduino_ROS_bridge.py]
2018-04-22 fix: possibly fixed digit check??
    [arduino_ROS_bridge.py]
2018-04-22 fix: check digit works, delete raspicam
    [arduino_ROS_bridge.py]
2018-05-03 fix: It all works on the new USB camera!
    [mmm.urdf.xacro]
2018-05-03 feat: launch file that only launches arduino_ros_bridge, fixed joint callback
    [arduino_ROS_bridge.py]
2018-05-03 feat: manual joint control
2018-05-06 feat: candy box mesh, markers PDF
    [candy box.stl]
2018-05-06 feat: tracks the candy box in real time, but this is a clumsy integration. Also recreated the MoveIt package, for good measure.
    [candy_box.stl, controllers.yaml, mmm.urdf.xacro]
2018-05-09 feat: defining targets script, controllers.yaml stuff
    [controllers.yaml]
2018-05-09 feat: Moveit actually works together with robot (again). It was a problem with not having the controller specified, and also because of the namespace.
    [controllers.yaml]
2018-05-15 feat: try to grab candy box fix: Arduino bridge continuously sends "activate joint" commands, since it seemed to fail to be received properly when I only sent it once...
    [arduino_ROS_bridge.py]
2018-05-17 feat: behavior.py now is simpler and just receives ros message commands feat: create minimal.launch fix: audio.launch uses playsound
    [arduino_ROS_bridge.py, audio.py]
2018-05-17 feat: playback ros bag file! feat: dance feat: janken feat: pick up (not enough voltage..) fix: audio node
    [Camera.cfg]
2018-05-17 feat: bot
    [2018_5_17.csv, all_received_messages.csv, dataset_okan.csv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]
2018-05-18 feat: REMOVE moveit stuff, lol feat: user recognition works! feat: random r2d2 sounds
    [phrases_okan.csv]
2018-05-18 feat: Image saver that runs on Python 2 (fuck you python 2 and cv_bridge... I mean, thank you very much for providing a way to convert sensor_msgs.msg/Image to opencv images.) feat: ball tracker. Sti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
    [arduino_ROS_bridge.py]
2018-05-18 add training data and phrases, deleted stuff
    [dataset_mmm.csv, dataset_okan.csv, dataset_okan_simple.csv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]
2018-05-18 Revert "add training data and phrases, deleted stuff"
    This reverts commit 91e9d334defd9d2c7ba685cdef1584e2342d2bb1.
    [dataset_mmm.csv, dataset_okan.csv, dataset_okan_simple.csv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]
2018-05-18 feat: bot without ROS
    [2018_5_17.csv, all_received_messages.csv, dataset_okan.csv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]
2018-05-19 feat: run behavior.py on RasPi
    [all_received_messages.csv, dataset_mmm.csv, dataset_okan.csv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]
2018-05-19 feat: I2C communication somewhat stable, as long as you push the reset button on the Arduino from time to time
2018-05-19 feat: added songs to dance to feat: much more snarky, interactive chat feat: relaxed timeout time fix: put in chatbot worker thread code inside rospy.is_shutdown() checking loop, in the hopes that th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
    [dataset_mmm.csv, phrases_mmm.csv]
